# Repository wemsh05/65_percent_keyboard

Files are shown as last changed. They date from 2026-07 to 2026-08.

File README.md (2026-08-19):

# My first Keyboard design

This 65% keyboard is the first time I designed a pcb of my own and safe to say that I am really proud of it. The reason that I started with a keyboard is that my first mechanical keyboard used the classic ANSI layout. While usable, an idea popped in my head: what if I make my own keyboard that has 4 keys to the left of the space bar just like the laptop keyboards, and here I am.  

---

# Project Overview

This project is a two-layer FR4 board with hot-swappable cherry MX keys realized with kalih's hot swap sockets. It features an on-board usb c 2.0 port with ESD. Its MCU is the ATMega32U4 and it features an AVR 6-pin ISP connector to program the MCU firmware. The board also has a reset button and copper-grounded mounting holes. 

This project is inspired by MasterZen's 65% keyboard tutorial. But there are major differences as I did not simply copy his design. First, his designed utilized soldered ALPS footprints that in my opinion has more space for the routing and therefore slightly easier to route. The kalih hot swap sockets caused a barrier that traces can't be wired through the sockets unlike the tutorial and that took some time to get used to. Since this is my first time doing this, I also have not mastered the art of routing so the vias are probably more than the same project done by someone more skilled. 

---

# Schematic

The following is the overall keyboard schematic, which doesn't deviate too much from the tutorial. Although it seems that power flags have changed from the older kicad version the tutorial was using to kicad 10. 

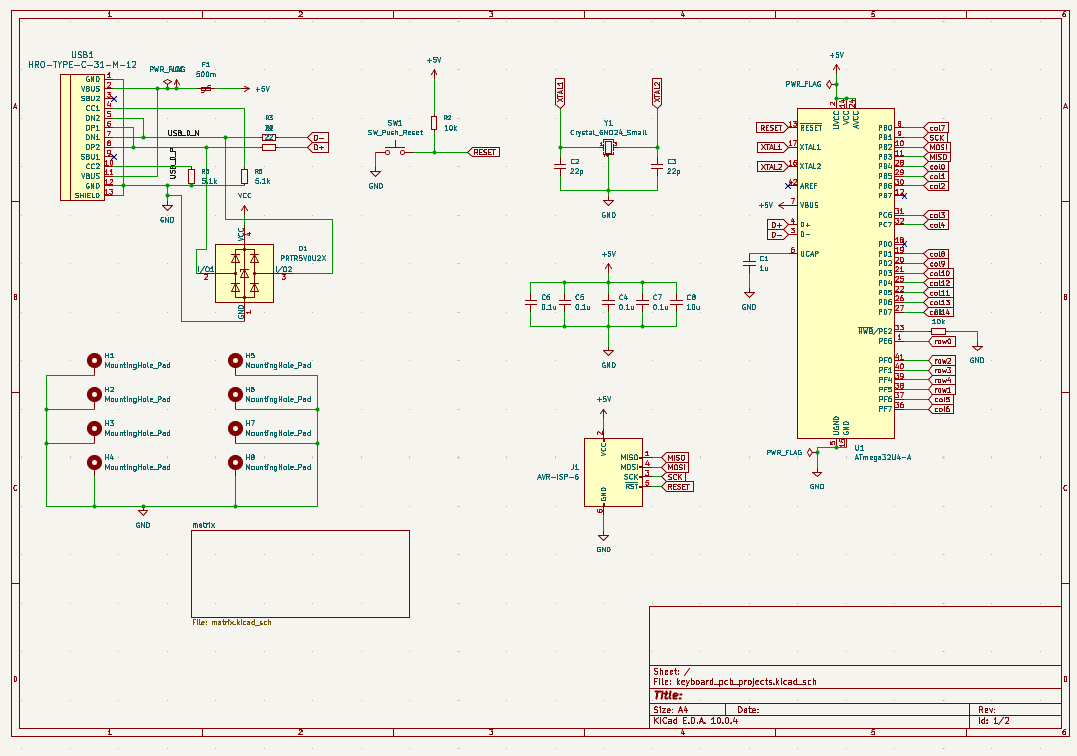
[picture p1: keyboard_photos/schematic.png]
Keyboard Schematic


The ESD protection device that I have on here is the PRTR5V0U2X, a device suitable for doing ESD protection for USB 2.0 devices. This was chosen because of ease of use and that it has a small package size. 

The AVR 6-pin ISP pin is added to flash the initial usb bootloader for future firmware uploads, it also provides a backup to not fully rely on the usb port for firmware uploads as bad firmware could render it useless. 

The grounded mounting hole pads are there because initially my plan is to eventually make an aluminum enclosure for it and these copper mounting hole pads could help with grounding. But in the event of a plastic or resin enclosure, the board would still not be in danger because of its existing grounding and ESD protection. 

---

# PCB layout

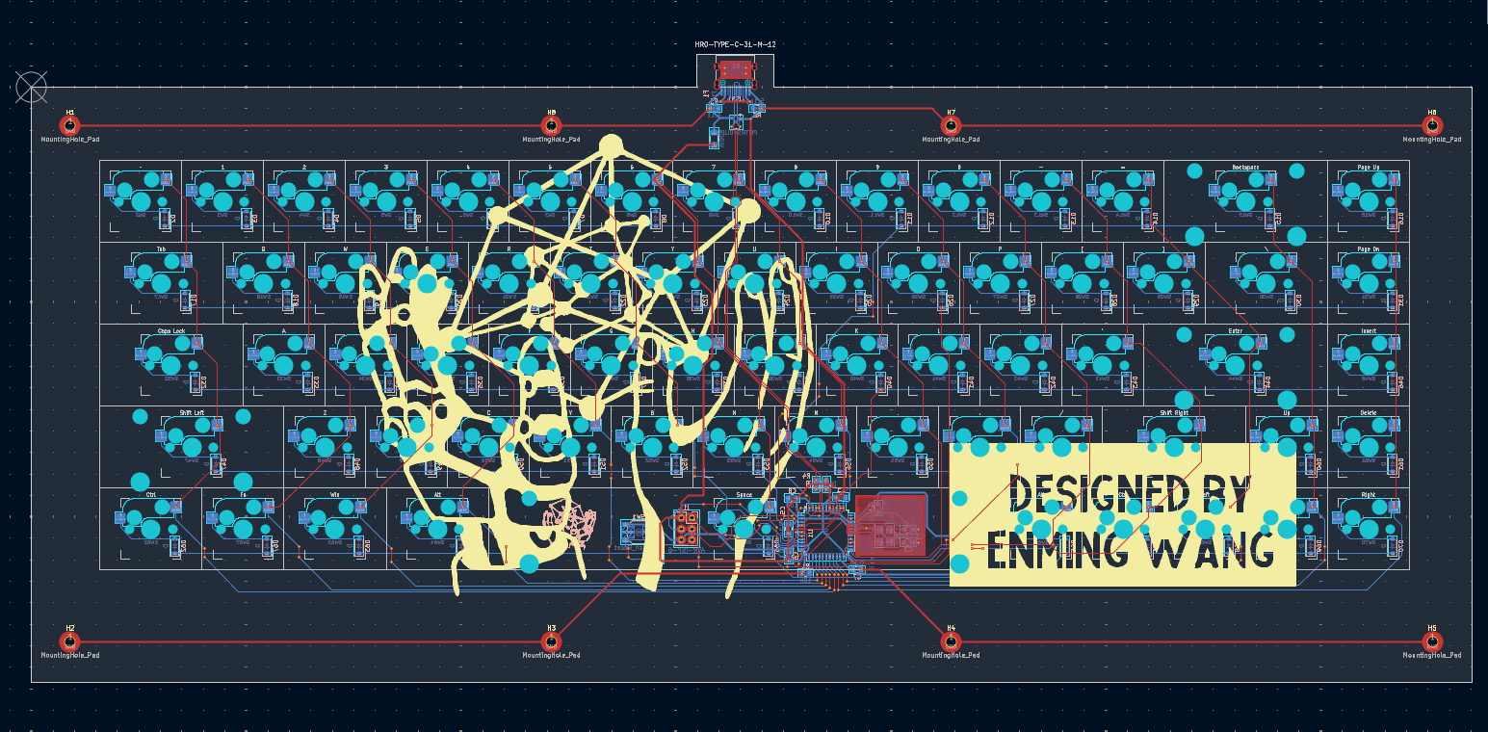
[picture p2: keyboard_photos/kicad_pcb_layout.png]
keyboard layout


My first layout finished with a lot of vias, a lot of which isn't really necessary on the hotswap pads themselves. But I would say that there are definitely more vias than I would like on the MCU pads and near the MCU. 

Regarding the grounding, my friend who does pcbs much more than me says that usually he fills both sides that have no traces with copper but Masterzen said that I don't need to cover both sides with copper as ground as that could amplify cross-talk. He mentioned that 4 layer boards and above have their dedicated ground layers so it wouldn't be an issue for them. 

---

# Silkscreen and 3D effects

Currently, the silkscreen remains a free-hand drawing of what I imagine the final prototype to be as I don't have time to improve it. 

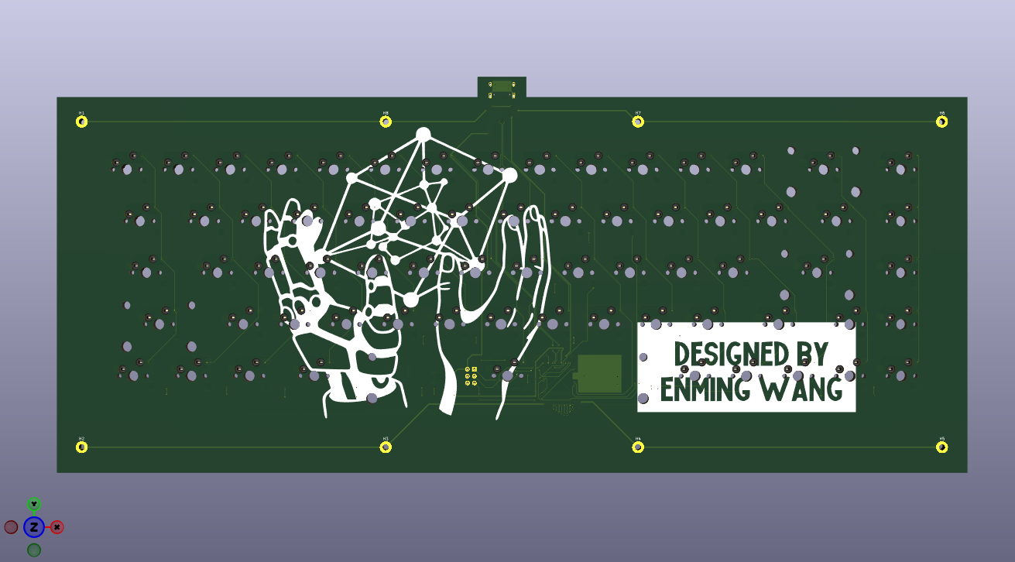
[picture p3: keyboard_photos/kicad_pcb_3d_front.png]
keyboard layout


But on the front of 3d effects, I did end up choosing red as the final board color since I wanted the color to stand out a bit more but the official purple color is too muted. 

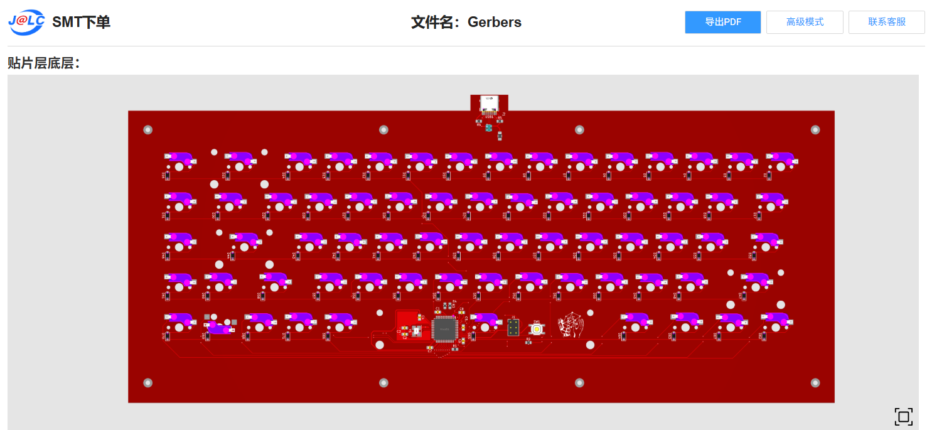
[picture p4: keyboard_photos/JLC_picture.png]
keyboard layout


---

# Manufactured pictures

(Update on 8/19/2026)
The keyboard is now fully manufactured and I did have to end up choosing a matte light black since the manufacturer didn't have purple. But it did also turn out that the color was nice. For my first ever pcb project, the overall size definitely had the potential for optimization, but I believe overall this was a successful project. 

The front side 
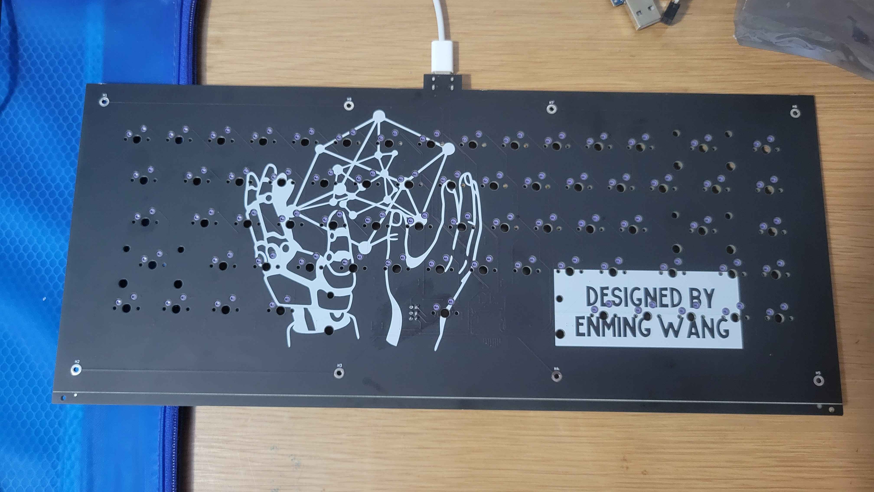
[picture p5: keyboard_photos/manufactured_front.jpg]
keyboard layout


The back side
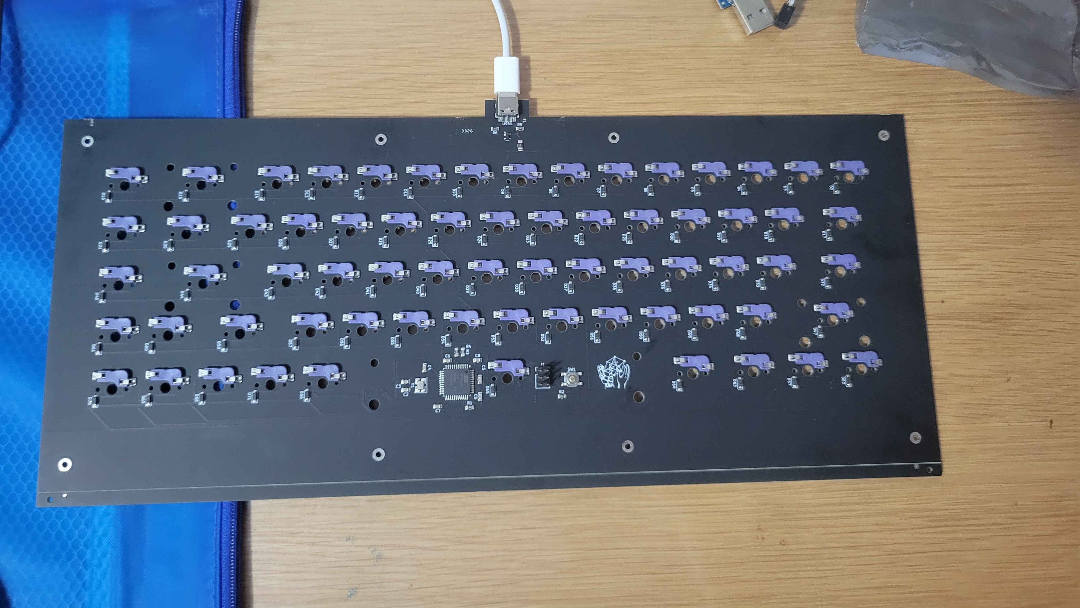
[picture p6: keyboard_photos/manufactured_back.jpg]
keyboard layout


---

# Firmware download success

I had to write the key matrix firmware for this board. Fortunately, the bootloader was already in the MCU which I somehow thought it wasn't. Currently I don't have the keys themselves to test multi-key rollover, but single keys do work:

Full Demo (https://www.youtube.com/watch?v=wM53zP1alu8)

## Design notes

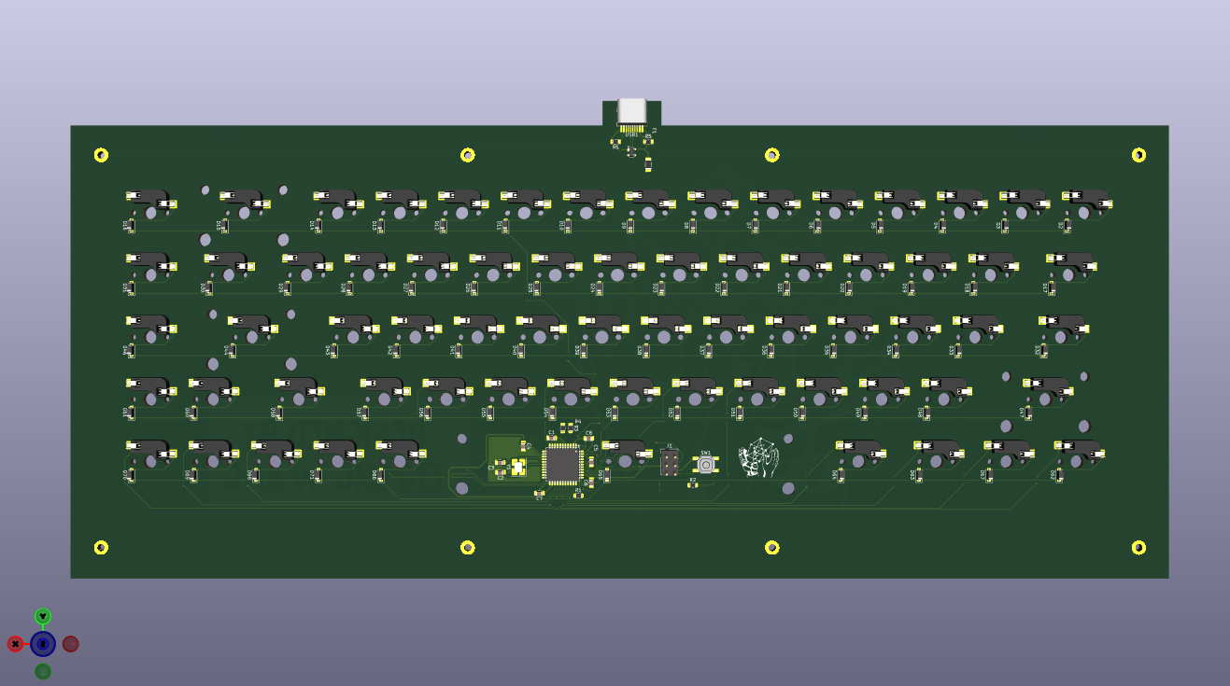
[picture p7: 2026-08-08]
keyboard_photos/kicad_pcb_3d_back.png

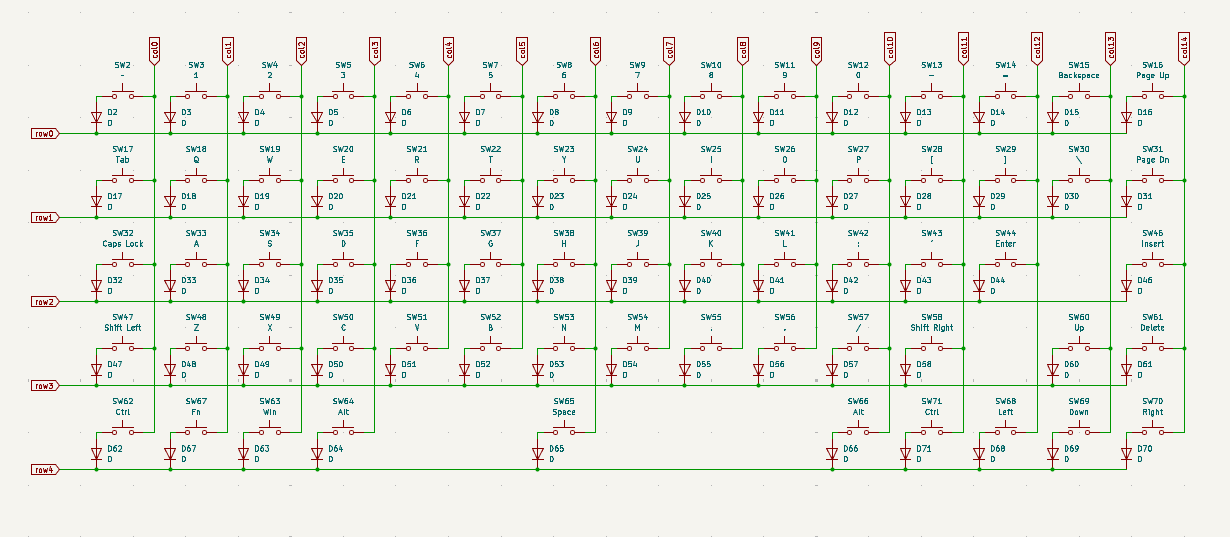
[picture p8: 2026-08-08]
keyboard_photos/key_matrix.png

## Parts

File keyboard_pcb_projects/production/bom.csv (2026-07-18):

Designator | Footprint | Quantity | Value | LCSC Part #
C1 | 0805 | 1 | 1u
C2, C3 | 0805 | 2 | 22p
C4, C5, C6, C7 | 0805 | 4 | 0.1u
C8 | 0805 | 1 | 10u
D1 | SOT-143 | 1 | PRTR5V0U2X
D10, D11, D12, D13, D14, D15, D16, D17, D18, D19, D2, D20, D21, D22, D23, D24, D25, D26, D27, D28, D29, D3, D30, D31, D32, D33, D34, D35, D36, D37, D38, D39, D4, D40, D41, D42, D43, D44, D46, D47, D48, D49, D5, D50, D51, D52, D53, D54, D55, D56, D57, D58, D6, D60, D61, D62, D63, D64, D65, D66, D67, D68, D69, D7, D70, D71, D8, D9 | D_SOD-123 | 68 | D
F1 | 1206 | 1 | 500m
J1 | PinHeader_2x03_P2.54mm_Vertical | 1 | AVR-ISP-6
R1, R2 | 0805 | 2 | 10k
R3, R4 | 0805 | 2 | 22
R5, R6 | 0805 | 2 | 5.1k
SW1 | SW_SPST_SKQG_WithStem | 1 | SW_Push_Reset
SW10 | MX-Hotswap-1U | 1 | 8
SW11 | MX-Hotswap-1U | 1 | 9
SW12 | MX-Hotswap-1U | 1 | 0
SW13 | MX-Hotswap-1U | 1 | -
SW14 | MX-Hotswap-1U | 1 | =
SW15 | MX-Hotswap-2U | 1 | Backspace
SW16 | MX-Hotswap-1U | 1 | Page Up
SW17 | MX-Hotswap-1.5U | 1 | Tab
SW18 | MX-Hotswap-1U | 1 | Q
SW19 | MX-Hotswap-1U | 1 | W
SW2 | MX-Hotswap-1U | 1 | ~
SW20 | MX-Hotswap-1U | 1 | E
SW21 | MX-Hotswap-1U | 1 | R
SW22 | MX-Hotswap-1U | 1 | T
SW23 | MX-Hotswap-1U | 1 | Y
SW24 | MX-Hotswap-1U | 1 | U
SW25 | MX-Hotswap-1U | 1 | I
SW26 | MX-Hotswap-1U | 1 | O
SW27 | MX-Hotswap-1U | 1 | P
SW28 | MX-Hotswap-1U | 1 | [
SW29 | MX-Hotswap-1U | 1 | ]
SW3 | MX-Hotswap-1U | 1 | 1
SW30 | MX-Hotswap-1.5U | 1 | \
SW31 | MX-Hotswap-1U | 1 | Page Dn
SW32 | MX-Hotswap-1.75U | 1 | Caps Lock
SW33 | MX-Hotswap-1U | 1 | A
SW34 | MX-Hotswap-1U | 1 | S
SW35 | MX-Hotswap-1U | 1 | D
SW36 | MX-Hotswap-1U | 1 | F
SW37 | MX-Hotswap-1U | 1 | G
SW38 | MX-Hotswap-1U | 1 | H
SW39 | MX-Hotswap-1U | 1 | J
SW4 | MX-Hotswap-1U | 1 | 2
SW40 | MX-Hotswap-1U | 1 | K
SW41 | MX-Hotswap-1U | 1 | L
SW42 | MX-Hotswap-1U | 1 | ;
SW43 | MX-Hotswap-1U | 1 | '
SW44 | MX-Hotswap-2.25U | 1 | Enter
SW46 | MX-Hotswap-1U | 1 | Insert
SW47 | MX-Hotswap-2.25U | 1 | Shift Left
SW48 | MX-Hotswap-1U | 1 | Z
SW49 | MX-Hotswap-1U | 1 | X
SW5 | MX-Hotswap-1U | 1 | 3
SW50 | MX-Hotswap-1U | 1 | C
SW51 | MX-Hotswap-1U | 1 | V
SW52 | MX-Hotswap-1U | 1 | B
SW53 | MX-Hotswap-1U | 1 | N
SW54 | MX-Hotswap-1U | 1 | M
SW55 | MX-Hotswap-1U | 1 | ,
SW56 | MX-Hotswap-1U | 1 | .
SW57 | MX-Hotswap-1U | 1 | /
SW58 | MX-Hotswap-1.75U | 1 | Shift Right
SW6 | MX-Hotswap-1U | 1 | 4
SW60 | MX-Hotswap-1U | 1 | Up
SW61 | MX-Hotswap-1U | 1 | Delete
SW62 | MX-Hotswap-1.25U | 1 | Ctrl
SW63 | MX-Hotswap-1.25U | 1 | Win
SW64 | MX-Hotswap-1.25U | 1 | Alt
SW65 | MX-Hotswap-6.25U | 1 | Space
SW66 | MX-Hotswap-1U | 1 | Alt
SW67 | MX-Hotswap-1U | 1 | Fn
SW68 | MX-Hotswap-1U | 1 | Left
SW69 | MX-Hotswap-1U | 1 | Down
SW7 | MX-Hotswap-1U | 1 | 5
SW70 | MX-Hotswap-1U | 1 | Right
SW71 | MX-Hotswap-1U | 1 | Ctrl
SW8 | MX-Hotswap-1U | 1 | 6
SW9 | MX-Hotswap-1U | 1 | 7
U1 | TQFP-44_10x10mm_P0.8mm | 1 | ATmega32U4-A
USB1 | HRO-TYPE-C-31-M-12-HandSoldering | 1 | HRO-TYPE-C-31-M-12
Y1 | Crystal_SMD_3225-4Pin_3.2x2.5mm_HandSoldering | 1 | Crystal_GND24_Small

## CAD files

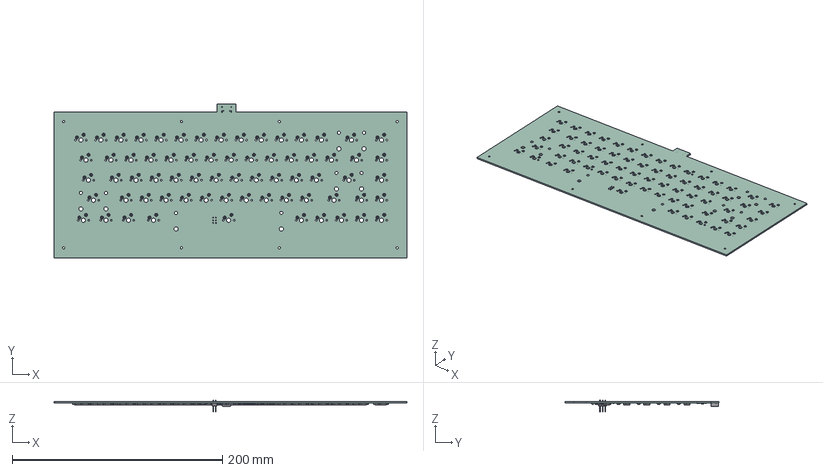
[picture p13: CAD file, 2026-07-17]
keyboard_pcb_projects/sixty_five_percent_keyboard.step
335.5 x 146.0 x 11.5 mm
Kailh Socket v12 x 68
R_0805_2012Metric x 6
D_SOD-123 x 68
PinHeader_2x03_P254mm_Vertical
C_0805_2012Metric x 8
Fuse_1206_3216Metric
HRO TYPE-C-31-M-12 v4
SOT-143
SW_SPST_SKQG_WithStem
Crystal_SMD_3225-4Pin_3.2x2.5mm
TQFP-44_10x10mm_P0.8mm
keyboard_pcb_projects_PCB

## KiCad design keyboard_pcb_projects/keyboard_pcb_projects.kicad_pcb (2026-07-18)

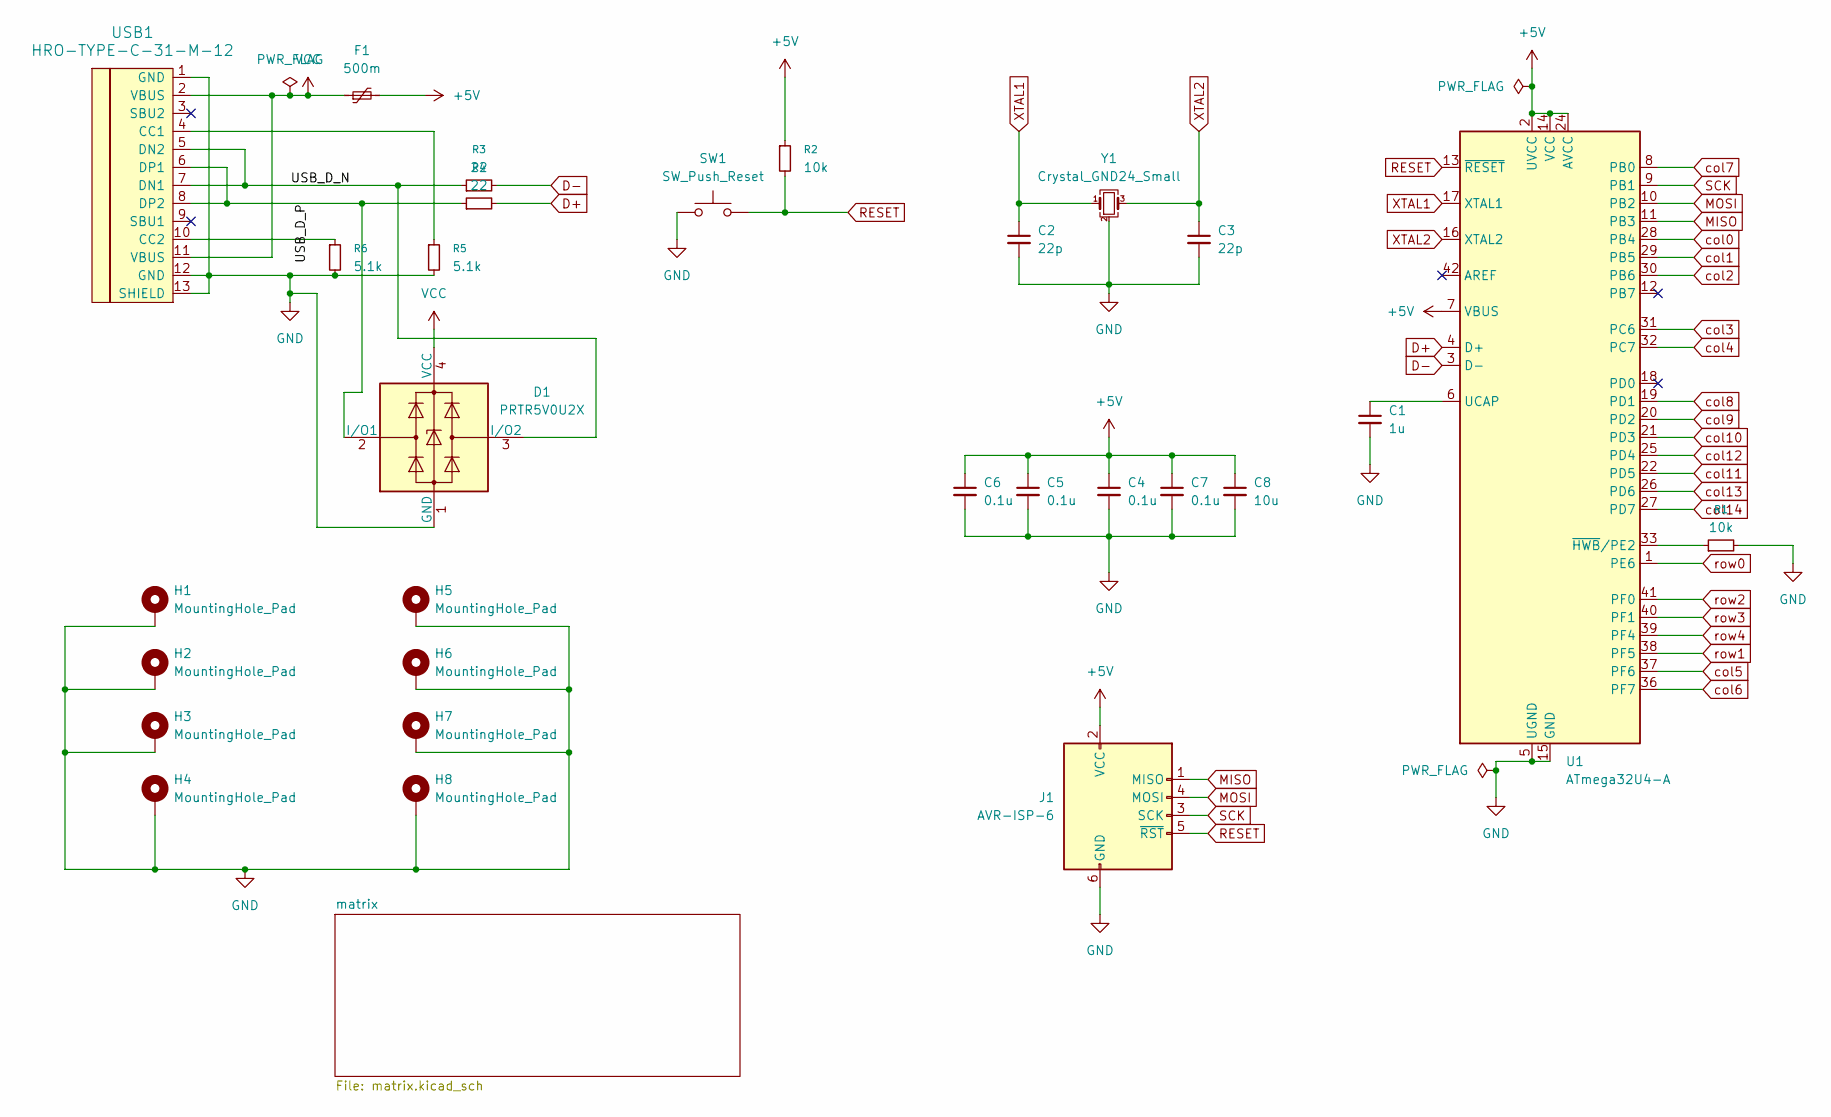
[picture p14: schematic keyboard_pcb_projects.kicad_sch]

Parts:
C1: 1u; C_0805_2012Metric_Pad1.18x1.45mm_HandSolder
C2, C3: 22p; C_0805_2012Metric_Pad1.18x1.45mm_HandSolder
C4, C5, C6, C7: 0.1u; C_0805_2012Metric_Pad1.18x1.45mm_HandSolder
C8: 10u; C_0805_2012Metric_Pad1.18x1.45mm_HandSolder
D1: PRTR5V0U2X; SOT-143
F1: 500m; Fuse_1206_3216Metric_Pad1.42x1.75mm_HandSolder
H1, H2, H3, H4, H5, H6, H7, H8: MountingHole_Pad; MountingHole_2.2mm_M2_Pad
J1: AVR-ISP-6; PinHeader_2x03_P2.54mm_Vertical
R1, R2: 10k; R_0805_2012Metric_Pad1.20x1.40mm_HandSolder
R3, R4: 22; R_0805_2012Metric_Pad1.20x1.40mm_HandSolder
R5, R6: 5.1k; R_0805_2012Metric_Pad1.20x1.40mm_HandSolder
SW1: SW_Push_Reset; SW_SPST_SKQG_WithStem
U1: ATmega32U4-A; TQFP-44_10x10mm_P0.8mm
USB1: HRO-TYPE-C-31-M-12; HRO-TYPE-C-31-M-12-HandSoldering
Y1: Crystal_GND24_Small; Crystal_SMD_3225-4Pin_3.2x2.5mm_HandSoldering

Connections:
+5V: C4.1, C5.1, C6.1, C7.1, C8.1, F1.2, J1.2 (VCC), R2.1, U1.2 (UVCC), U1.7 (VBUS), U1.14 (VCC), U1.24 (AVCC), U1.34 (VCC), U1.44 (AVCC)
/USB_D_N: D1.3 (I/O2), R3.1, USB1.5 (DN2), USB1.7 (DN1)
/USB_D_P: D1.2 (I/O1), R4.1, USB1.6 (DP1), USB1.8 (DP2)
D+: R4.2, U1.4 (D+)
D-: R3.2, U1.3 (D-)
GND: C1.2, C2.2, C3.2, C4.2, C5.2, C6.2, C7.2, C8.2, D1.1 (GND), H1.1 (1_1), H2.1 (1_1), H3.1 (1_1), H4.1 (1_1), H5.1 (1_1), H6.1 (1_1), H7.1 (1_1), H8.1 (1_1), J1.6 (GND), R1.2, R5.2, R6.2, SW1.1, U1.5 (UGND), U1.15 (GND), U1.23 (GND), U1.35 (GND), U1.43 (GND), USB1.1 (GND), USB1.12 (GND), USB1.13 (SHIELD), Y1.2 (G), Y1.4 (G)
MISO: J1.1 (MISO), U1.11 (PB3)
MOSI: J1.4 (MOSI), U1.10 (PB2)
unnamed: C1.1, U1.6 (UCAP)
unnamed: R1.1, U1.33 (~HWB/PE2)
unnamed: R5.1, USB1.4 (CC1)
unnamed: R6.1, USB1.10 (CC2)
RESET: J1.5 (~RST), R2.2, SW1.2, U1.13 (~RESET)
SCK: J1.3 (SCK), U1.9 (PB1)
VCC: D1.4 (VCC), F1.1, USB1.2 (VBUS), USB1.11 (VBUS)
XTAL1: C2.1, U1.17 (XTAL1), Y1.1
XTAL2: C3.1, U1.16 (XTAL2), Y1.3
col0: U1.28 (PB4); also elsewhere on the board
col1: U1.29 (PB5); also elsewhere on the board
col2: U1.30 (PB6); also elsewhere on the board
col3: U1.31 (PC6); also elsewhere on the board
col4: U1.32 (PC7); also elsewhere on the board
col5: U1.37 (PF6); also elsewhere on the board
col6: U1.36 (PF7); also elsewhere on the board
col7: U1.8 (PB0); also elsewhere on the board
col8: U1.19 (PD1); also elsewhere on the board
col9: U1.20 (PD2); also elsewhere on the board
col10: U1.21 (PD3); also elsewhere on the board
col11: U1.22 (PD5); also elsewhere on the board
col12: U1.25 (PD4); also elsewhere on the board
col13: U1.26 (PD6); also elsewhere on the board
col14: U1.27 (PD7); also elsewhere on the board
row0: U1.1 (PE6); also elsewhere on the board
row1: U1.38 (PF5); also elsewhere on the board
row2: U1.41 (PF0); also elsewhere on the board
row3: U1.40 (PF1); also elsewhere on the board
row4: U1.39 (PF4); also elsewhere on the board

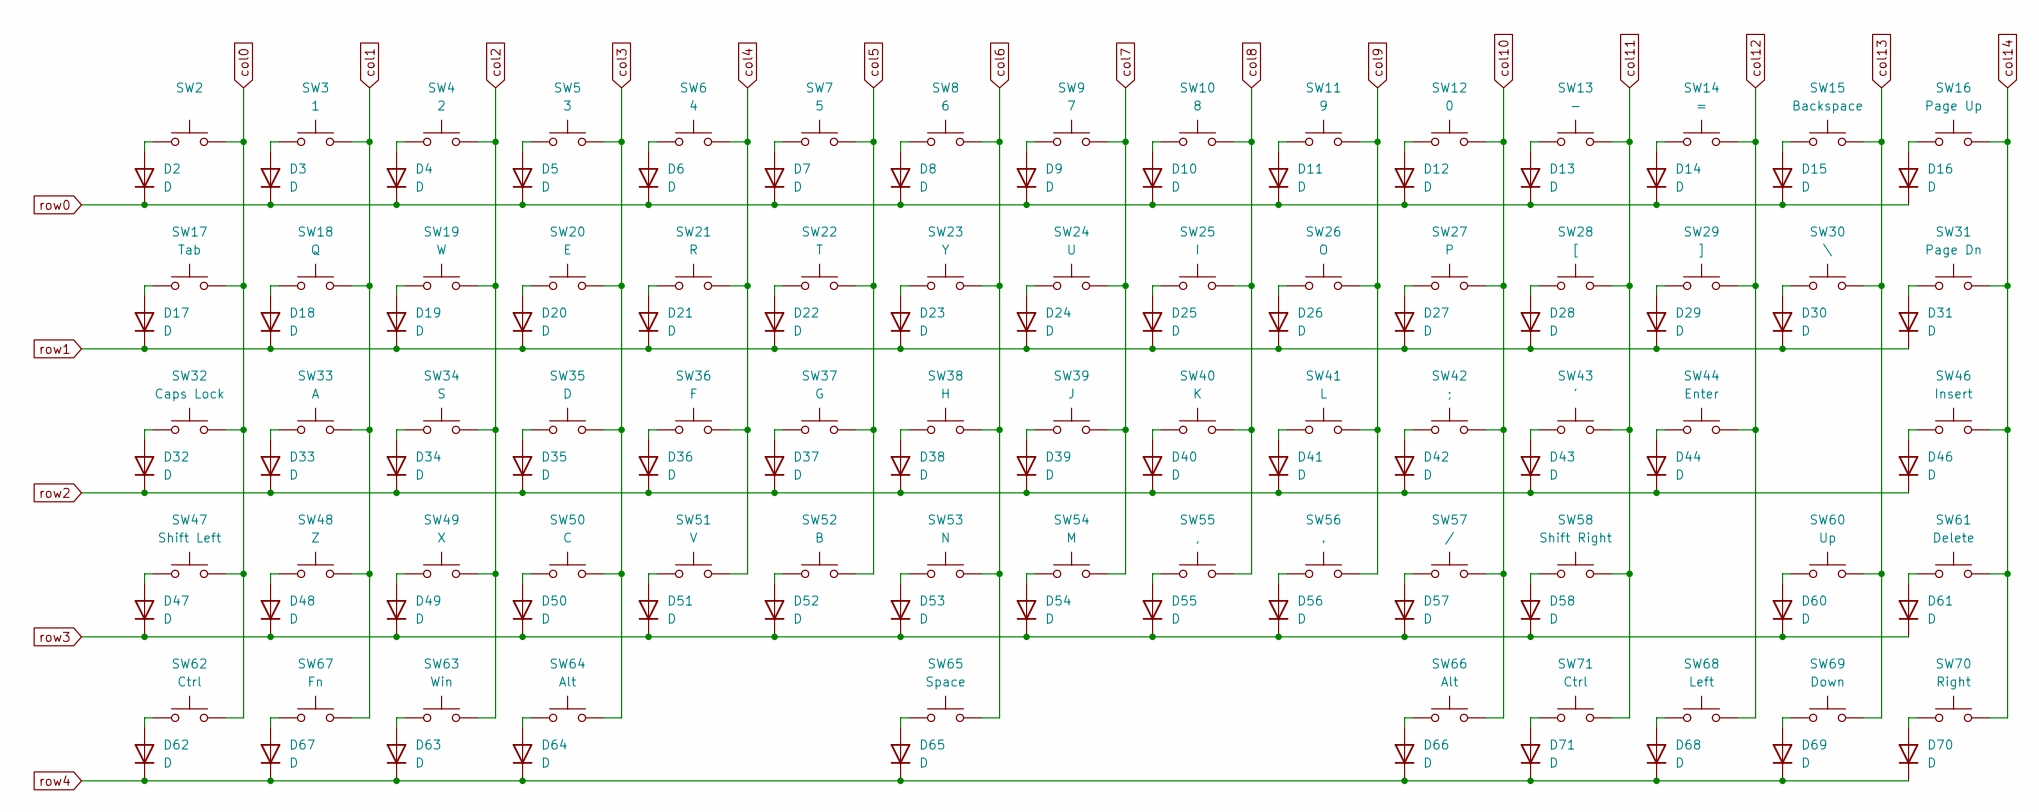
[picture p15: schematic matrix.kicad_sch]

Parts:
D2, D3, D4, D5, D6, D7, D8, D9, D10, D11, D12, D13, D14, D15, D16, D17, D18, D19, D20, D21, D22, D23, D24, D25, D26, D27, D28, D29, D30, D31, D32, D33, D34, D35, D36, D37, D38, D39, D40, D41, D42, D43, D44, D46, D47, D48, D49, D50, D51, D52, D53, D54, D55, D56, D57, D58, D60, D61, D62, D63, D64, D65, D66, D67, D68, D69, D70, D71: D; D_SOD-123
SW2: MX-Hotswap-1U
SW3: 1; MX-Hotswap-1U
SW4: 2; MX-Hotswap-1U
SW5: 3; MX-Hotswap-1U
SW6: 4; MX-Hotswap-1U
SW7: 5; MX-Hotswap-1U
SW8: 6; MX-Hotswap-1U
SW9: 7; MX-Hotswap-1U
SW10: 8; MX-Hotswap-1U
SW11: 9; MX-Hotswap-1U
SW12: 0; MX-Hotswap-1U
SW13: -; MX-Hotswap-1U
SW14: =; MX-Hotswap-1U
SW15: Backspace; MX-Hotswap-2U
SW16: Page Up; MX-Hotswap-1U
SW17: Tab; MX-Hotswap-1.5U
SW18: Q; MX-Hotswap-1U
SW19: W; MX-Hotswap-1U
SW20: E; MX-Hotswap-1U
SW21: R; MX-Hotswap-1U
SW22: T; MX-Hotswap-1U
SW23: Y; MX-Hotswap-1U
SW24: U; MX-Hotswap-1U
SW25: I; MX-Hotswap-1U
SW26: O; MX-Hotswap-1U
SW27: P; MX-Hotswap-1U
SW28: [; MX-Hotswap-1U
SW29: ]; MX-Hotswap-1U
SW30: \; MX-Hotswap-1.5U
SW31: Page Dn; MX-Hotswap-1U
SW32: Caps Lock; MX-Hotswap-1.75U
SW33: A; MX-Hotswap-1U
SW34: S; MX-Hotswap-1U
SW35: D; MX-Hotswap-1U
SW36: F; MX-Hotswap-1U
SW37: G; MX-Hotswap-1U
SW38: H; MX-Hotswap-1U
SW39: J; MX-Hotswap-1U
SW40: K; MX-Hotswap-1U
SW41: L; MX-Hotswap-1U
SW42: ;; MX-Hotswap-1U
SW43: '; MX-Hotswap-1U
SW44: Enter; MX-Hotswap-2.25U
SW46: Insert; MX-Hotswap-1U
SW47: Shift Left; MX-Hotswap-2.25U
SW48: Z; MX-Hotswap-1U
SW49: X; MX-Hotswap-1U
SW50: C; MX-Hotswap-1U
SW51: V; MX-Hotswap-1U
SW52: B; MX-Hotswap-1U
SW53: N; MX-Hotswap-1U
SW54: M; MX-Hotswap-1U
SW55: ,; MX-Hotswap-1U
SW56: .; MX-Hotswap-1U
SW57: /; MX-Hotswap-1U
SW58: Shift Right; MX-Hotswap-1.75U
SW60: Up; MX-Hotswap-1U
SW61: Delete; MX-Hotswap-1U
SW62: Ctrl; MX-Hotswap-1.25U
SW63: Win; MX-Hotswap-1.25U
SW64: Alt; MX-Hotswap-1.25U
SW65: Space; MX-Hotswap-6.25U
SW66: Alt; MX-Hotswap-1U
SW67: Fn; MX-Hotswap-1U
SW68: Left; MX-Hotswap-1U
SW69: Down; MX-Hotswap-1U
SW70: Right; MX-Hotswap-1U
SW71: Ctrl; MX-Hotswap-1U

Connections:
unnamed: D2.2 (A), SW2.1
unnamed: D3.2 (A), SW3.1
unnamed: D4.2 (A), SW4.1
unnamed: D5.2 (A), SW5.1
unnamed: D6.2 (A), SW6.1
unnamed: D7.2 (A), SW7.1
unnamed: D8.2 (A), SW8.1
unnamed: D9.2 (A), SW9.1
unnamed: D10.2 (A), SW10.1
unnamed: D11.2 (A), SW11.1
unnamed: D12.2 (A), SW12.1
unnamed: D13.2 (A), SW13.1
unnamed: D14.2 (A), SW14.1
unnamed: D15.2 (A), SW15.1
unnamed: D16.2 (A), SW16.1
unnamed: D17.2 (A), SW17.1
unnamed: D18.2 (A), SW18.1
unnamed: D19.2 (A), SW19.1
unnamed: D20.2 (A), SW20.1
unnamed: D21.2 (A), SW21.1
unnamed: D22.2 (A), SW22.1
unnamed: D23.2 (A), SW23.1
unnamed: D24.2 (A), SW24.1
unnamed: D25.2 (A), SW25.1
unnamed: D26.2 (A), SW26.1
unnamed: D27.2 (A), SW27.1
unnamed: D28.2 (A), SW28.1
unnamed: D29.2 (A), SW29.1
unnamed: D30.2 (A), SW30.1
unnamed: D31.2 (A), SW31.1
unnamed: D32.2 (A), SW32.1
unnamed: D33.2 (A), SW33.1
unnamed: D34.2 (A), SW34.1
unnamed: D35.2 (A), SW35.1
unnamed: D36.2 (A), SW36.1
unnamed: D37.2 (A), SW37.1
unnamed: D38.2 (A), SW38.1
unnamed: D39.2 (A), SW39.1
unnamed: D40.2 (A), SW40.1
unnamed: D41.2 (A), SW41.1
unnamed: D42.2 (A), SW42.1
unnamed: D43.2 (A), SW43.1
unnamed: D44.2 (A), SW44.1
unnamed: D46.2 (A), SW46.1
unnamed: D47.2 (A), SW47.1
unnamed: D48.2 (A), SW48.1
unnamed: D49.2 (A), SW49.1
unnamed: D50.2 (A), SW50.1
unnamed: D51.2 (A), SW51.1
unnamed: D52.2 (A), SW52.1
unnamed: D53.2 (A), SW53.1
unnamed: D54.2 (A), SW54.1
unnamed: D55.2 (A), SW55.1
unnamed: D56.2 (A), SW56.1
unnamed: D57.2 (A), SW57.1
unnamed: D58.2 (A), SW58.1
unnamed: D60.2 (A), SW60.1
unnamed: D61.2 (A), SW61.1
unnamed: D62.2 (A), SW62.1
unnamed: D63.2 (A), SW63.1
unnamed: D64.2 (A), SW64.1
unnamed: D65.2 (A), SW65.1
unnamed: D66.2 (A), SW66.1
unnamed: D67.2 (A), SW67.1
unnamed: D68.2 (A), SW68.1
unnamed: D69.2 (A), SW69.1
unnamed: D70.2 (A), SW70.1
unnamed: D71.2 (A), SW71.1
col0: SW2.2, SW17.2, SW32.2, SW47.2, SW62.2; also elsewhere on the board
col1: SW3.2, SW18.2, SW33.2, SW48.2, SW67.2; also elsewhere on the board
col2: SW4.2, SW19.2, SW34.2, SW49.2, SW63.2; also elsewhere on the board
col3: SW5.2, SW20.2, SW35.2, SW50.2, SW64.2; also elsewhere on the board
col4: SW6.2, SW21.2, SW36.2, SW51.2; also elsewhere on the board
col5: SW7.2, SW22.2, SW37.2, SW52.2; also elsewhere on the board
col6: SW8.2, SW23.2, SW38.2, SW53.2, SW65.2; also elsewhere on the board
col7: SW9.2, SW24.2, SW39.2, SW54.2; also elsewhere on the board
col8: SW10.2, SW25.2, SW40.2, SW55.2; also elsewhere on the board
col9: SW11.2, SW26.2, SW41.2, SW56.2; also elsewhere on the board
col10: SW12.2, SW27.2, SW42.2, SW57.2, SW66.2; also elsewhere on the board
col11: SW13.2, SW28.2, SW43.2, SW58.2, SW71.2; also elsewhere on the board
col12: SW14.2, SW29.2, SW44.2, SW68.2; also elsewhere on the board
col13: SW15.2, SW30.2, SW60.2, SW69.2; also elsewhere on the board
col14: SW16.2, SW31.2, SW46.2, SW61.2, SW70.2; also elsewhere on the board
row0: D2.1 (K), D3.1 (K), D4.1 (K), D5.1 (K), D6.1 (K), D7.1 (K), D8.1 (K), D9.1 (K), D10.1 (K), D11.1 (K), D12.1 (K), D13.1 (K), D14.1 (K), D15.1 (K), D16.1 (K); also elsewhere on the board
row1: D17.1 (K), D18.1 (K), D19.1 (K), D20.1 (K), D21.1 (K), D22.1 (K), D23.1 (K), D24.1 (K), D25.1 (K), D26.1 (K), D27.1 (K), D28.1 (K), D29.1 (K), D30.1 (K), D31.1 (K); also elsewhere on the board
row2: D32.1 (K), D33.1 (K), D34.1 (K), D35.1 (K), D36.1 (K), D37.1 (K), D38.1 (K), D39.1 (K), D40.1 (K), D41.1 (K), D42.1 (K), D43.1 (K), D44.1 (K), D46.1 (K); also elsewhere on the board
row3: D47.1 (K), D48.1 (K), D49.1 (K), D50.1 (K), D51.1 (K), D52.1 (K), D53.1 (K), D54.1 (K), D55.1 (K), D56.1 (K), D57.1 (K), D58.1 (K), D60.1 (K), D61.1 (K); also elsewhere on the board
row4: D62.1 (K), D63.1 (K), D64.1 (K), D65.1 (K), D66.1 (K), D67.1 (K), D68.1 (K), D69.1 (K), D70.1 (K), D71.1 (K); also elsewhere on the board

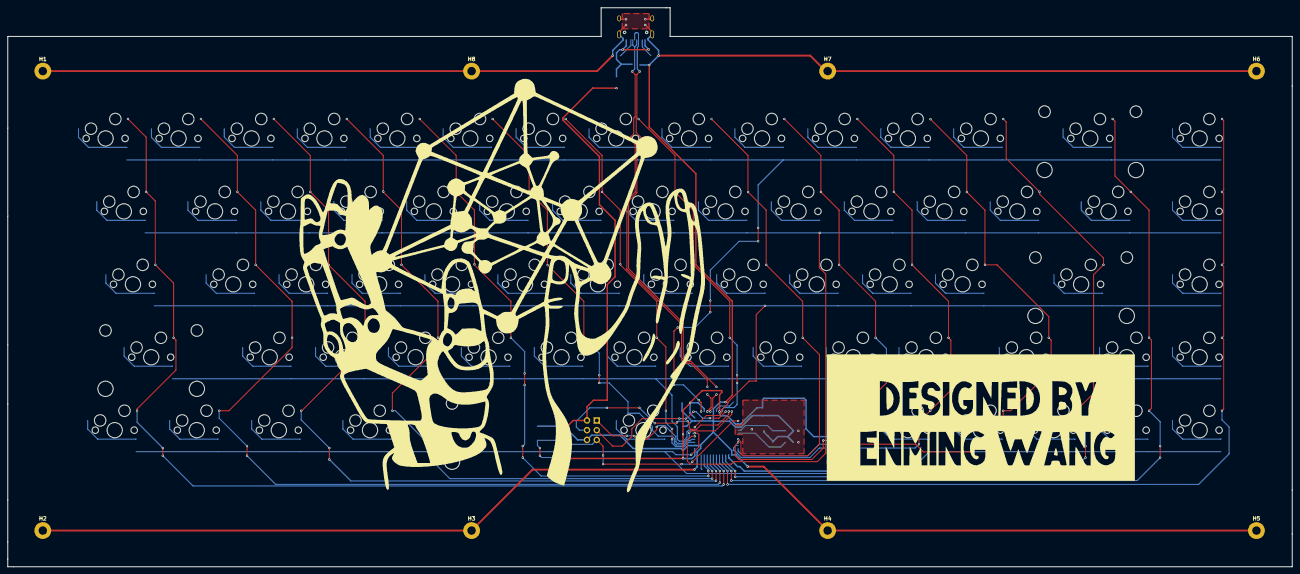
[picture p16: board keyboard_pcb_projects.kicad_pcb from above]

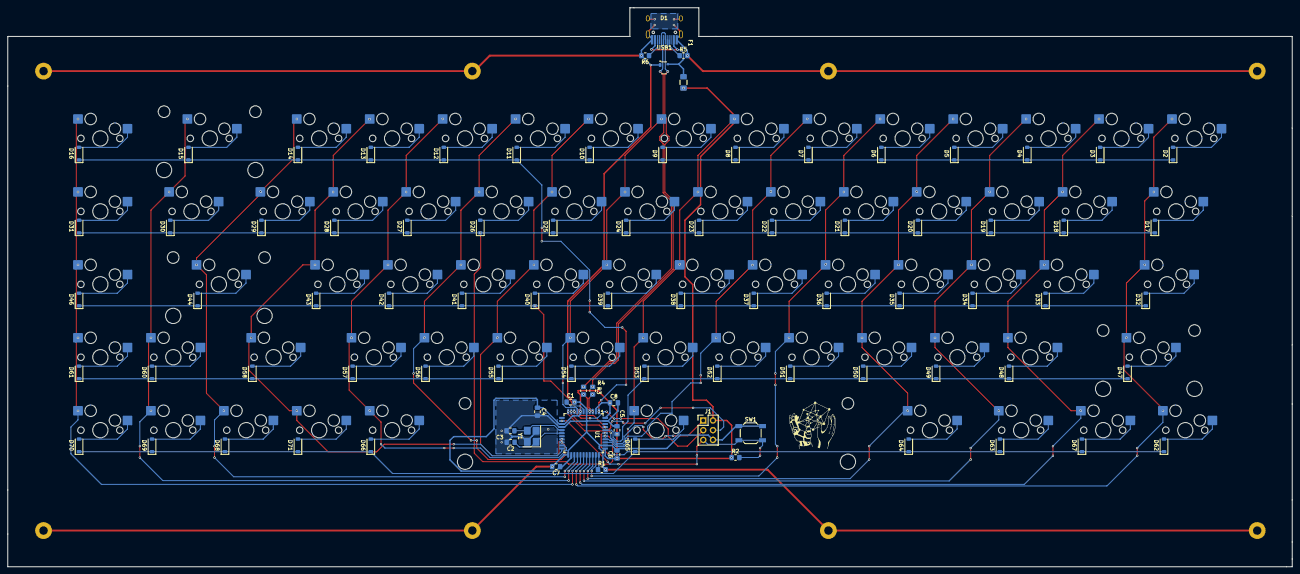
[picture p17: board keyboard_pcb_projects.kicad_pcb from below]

Board: 2 copper layers, 335.5 x 146.0 mm, 165 parts (157 on the bottom side), 105 nets.

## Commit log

2026-06-18 finally wired up two of the positive ends of the usb controller
    [keyboard_pcb_projects.kicad_pcb]
2026-07-02 More wiring progress
    [keyboard_pcb_projects.kicad_pcb, keyboard_pcb_projects.kicad_sch]
2026-07-13 synchronizing between OS workspaces
    [keyboard_pcb_projects.kicad_pcb]
2026-07-14 finally cleared all errors but the inherent usbc port sizing issue
    [keyboard_pcb_projects.kicad_pcb]
2026-07-14 ALL DRC passed after changing usb c footprint min distance from 0.2 to 0.15
    [keyboard_pcb_projects.kicad_pcb]
2026-07-14 new board sizing
    [keyboard_pcb_projects.kicad_pcb]
2026-07-17 Added copper padded mounting hole and exported STEP file for the board
    [keyboard_pcb_projects.kicad_pcb, keyboard_pcb_projects.kicad_sch, sixty_five_percent_keyboard.step]
2026-07-17 Added Silkscreen decorations to the board
    [keyboard_pcb_projects.kicad_pcb]
2026-07-18 Gerbers and production files ready
    [bom.csv, designators.csv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]
2026-08-09 readme finished, further additions will be added once the board is manufactured
2026-08-19 added keyboard firmware and pictures for the manufactured board
2026-08-19 updated pictures for manufactured board
